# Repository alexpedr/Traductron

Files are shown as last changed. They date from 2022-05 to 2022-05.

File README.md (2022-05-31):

# Traductron



**Tabla de contenidos**
- [¿Qué es esto?](#id0)
- [Objetivo](#id8)
- [Componentes](#id1)
- [Circuito Hardware](#id9)
- [Arquitectura Sofware](#id10)
- [Requisitos](#id11)
- [Documentación](#id2)
- [Modo de empleo](#id3)
- [Autores](#id6)
- [Bibliografía](#id7)

## ¿Qué es esto? 
Traductron, como su propio nombre indica, traduce el Lenguaje de Signos Español a audio mediante una cámara.

El robot tiene la cámara en un brazo móvil. Este brazo baja y sube en función de la posición que capta del tronco superior (utilizando MediaPipe). Traductron también gira a la derecha o a la izquierda sobre sí mismo, así nunca perderá a la persona.

Si cuando el robot se enciende no encuentra a la persona, gira sobre sí mismo hasta encontrarla y realiza el procedimiento anterior para no perderla. Una vez encontrada, hace la traducción detectando la mano mediante MediPipe y la emite por el altavoz y repite el proceso en bucle.  

## Objetivo 
Nuestro objetivo es facilitar a las personas que se comunican mediante Lenguaje de Signos a mantener conversaciones con otras que no conozcan el lenguaje.

Buscamos que este colectivo gane independencia y que no tenga que disponer de un intérprete o de un familiar para poder hacer tareas cuotidianas como por ejemplo, ir a hacer una transacción a un banco. 

## Componentes 
El hardware que hemos usado para nuestro robot prototipo son los siguientes:

- 2 Motores Micro Metal LP
- 2 Ruedas base 
- Controlador de motores L289n
- Motor paso a paso 28BYJ-48
- Raspberry pi zero
- Cámara raspberry pi 
- Altavoz
- Amplificador
- Power Bank
- Pilas 9V
- Rueda loca metálica 
- Piezas 3D



No son los ideales, ya que tuvimos que escogerlos al principio del proyecto y no sabíamos bien bien cuáles iban mejor con nuestro software. También teníamos que adaptarnos a un presupuesto de 100 € proporcionado por la universidad.

Cabe destacar que, como usamos Mediapipe, la raspberry pi zero no es aconsejable usarla, por el hecho de que no se puede instalar esta librería en ella.

## Circuito Hardware 
Este es un circuito orientativo con nuestros componentes.



## Arquitectura Sofware
Así es como funciona nuesto robot traductron. Está dividido en los siguientes módulos:



1. Camara
Cada 1,5 segundos aproximadamente la camara toma fotos y estas se pasan al módulo de detector de tronco superior.

2. Detector tronco superior



Para realizar el movimiento de desplazamiento del robot y el de subir y bajar el brazo con la cámara, usamos también la librería MediaPipe, en este caso la opción de detectar solo el tronco superior.

De esta manera, creamos un documento de texto en el cual escribiremos 8 movimientos:

- Left - Up
- Left- Down
- Left
- Up
- Down
- Right - Up
- Right - Down
- Right

Este documento se pasa al módulo de movimiento.

3. Movimiento

A partir de los valores del documento, el robot se moverá de manera correspondiente. Una vez posicionado, se accede al módulo de detector de manos y traducción. Y se repite el procedimiento en bucle.

4. Detector de manos


A partir de la librería “MediaPipe”, detectamos los puntos de control de la mano y concretamente las coordenadas X e Y de cada uno de los puntos. Con este detector creamos de 0 nuestro dataset para poder entrenar posteriormente la Red Neuronal. 

5. Red Neuronal

A través de la librería sklearn podemos entrenar una red neuronal con la función MLPclassifier() donde le pasamos el Dataset con todas las letras y sus respectivas etiquetas. 

6. Salida de audio 

A través de las librerías gtts y playsound podemos reproducir, mediante audio, las letras en signos que le vayamos enseñando a la cámara. 
Creamos una función que, pasada la etiqueta de la letra, la pase al código ASCII y después la convierta a tipo char. Una vez hecho esto, le pasamos la letra a la función gTTS(), que grabará el audio en español. Guardamos el resultado en un archivo .mp3 y después con la función playsound() reproducimos el audio. 

## Requisitos 
- [NumPy](https://numpy.org/)
- [Pandas](https://aprendeconalf.es/docencia/python/manual/pandas/)
- [gTTs](https://pypi.org/project/gTTS/)
- [playSound](https://pypi.org/project/playsound/)
- [cv2](https://pypi.org/project/cv2-tools/)
- [MediaPipe](https://pypi.org/project/mediapipe/)
- [Pickle](https://docs.python.org/es/3/library/pickle.html)
- [sklearn](https://scikit-learn.org/stable/install.html)
- [Math](https://docs.python.org/es/3.10/library/math.html)
- [Copy](https://docs.python.org/es/3/library/copy.html)
- [Time](https://docs.python.org/es/3/library/time.html)

## Documentación 
Traductron, de momento, solo realiza la traducción del abecedario del Lenguaje de Signos Español.



Para poder hacer esto de manera correcta, tuvimos que hacer algunos cambios.

1. Hacer las letras sin movimiento, ya que no pudimos procesarlo.
2. Eliminamos las letras no necesárias, como: 'LL', 'RR', 'Ñ' y 'CH'.
3. Modificamos los signos de letras las letras que se confundian con otras.
4. Así ha quedado el abecedario que traduce Traductron.



## Modo de empleo 

En el caso de ejecutarlo en ordenador: 

1. Clonar  repositorio
2. Instalar librerias necesarias
3. Ejecutar los archivos en el siguiente orden:

  - 3.1.  Ejecutamos archivo "pythonPrueba2.py
    > Utilizamos este archivo para crear el DataSet, utilizando el findDetector.
  - 3.2. Ejecutamos el archivo "concatenarTablas.py"
    > Creamos un único archivo con todos los valores de las letras que hemos generado anteriormente.
  - 3.3. Ejecutamos el archivo  "redNeuronal.py"
    > Nos devuelve un valor de Accuracy para poder analizar la precisión de nuestro detector y generar un archivo sav que será la red neuronal que se utilizará.
  - 3.4. Ejecutamos el archivo "intentoTraductorFinal.py"
    > Utilizamos de nuevo el handDetector para el momento de detectar los puntos y pasamos los puntos a la red neuronal, que esta nos devuelve que letra es y reproducimos por audio.
 
 Una vez ejecutados estos archivos con el último de ellos podemos empezar a traducir
 
 (Los puntos 3.1, 3.2 y 3.3 no son necesarios de ejecutar, ya que proporcionamos una red neuronal y un dataset).

  4. En el caso de no disponer de una raspberry pi 3 o 4, como en nuestro caso, puedes usar las carpetas CLIENTE y SERVIDOR. El cliente se guardará en la raspberry y el servidor en tu ordenador. 
 
El cliente coje una fotografía creada por la cámara, la guarda y la envía al ordenador mediante sockets. El ordenador usará MediaPipe sobre esa foto recibida, clasifica ese signo y envía el resultado al altavoz. Una vez hecho esto, detecta el tronco superior y dependiendo de la posición de la persona, enviará un documento de texto u otro al módulo de movimiento, que se encuentra en la raspberry.

## Autores 

- Àlex Pedrola González
- Susana Sánchez Ropero
- Paula Martín Merino
- Pablo Ezequiel Britos

## Bibliografía 
This project has been inspired by the following Internet projects:

- [https://www.xataka.com/aplicaciones/asi-showleap-traductor-lengua-signos-a-texto-voz-tiempo-real-esta-cada-vez-cerca ](https://www.xataka.com/aplicaciones/asi-showleap-traductor-lengua-signos-a-texto-voz-tiempo-real-esta-cada-vez-cerca )

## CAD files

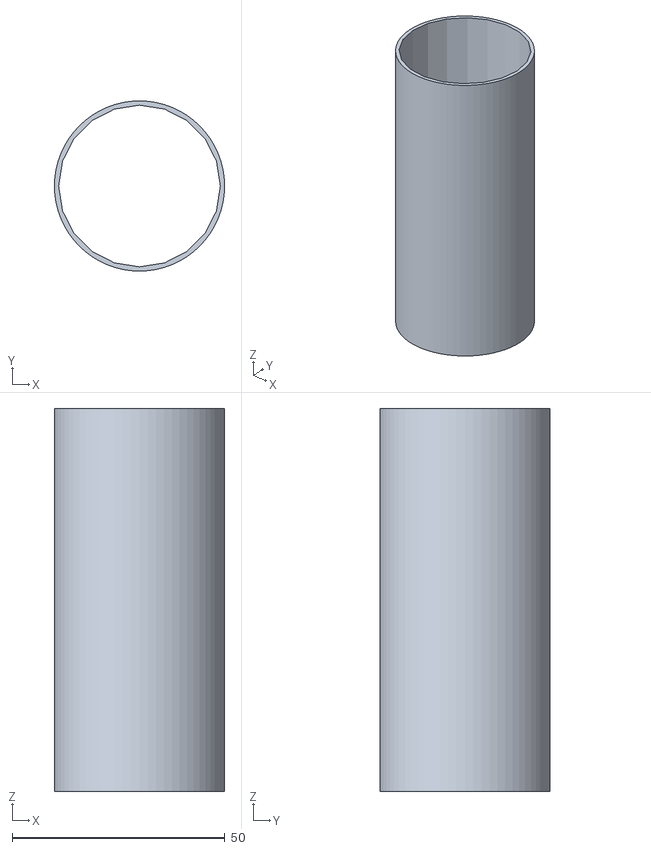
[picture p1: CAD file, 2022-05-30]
PIEZAS 3D/brazo.stl
40.0 x 40.0 x 90.0

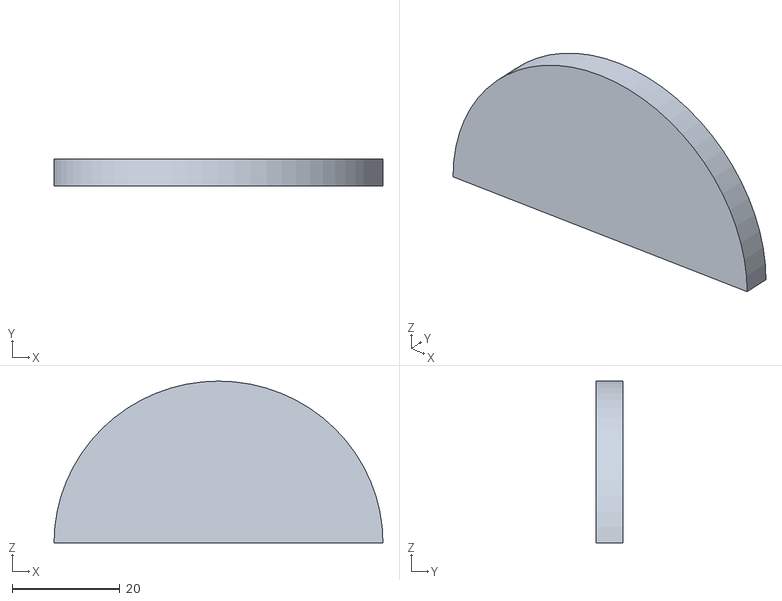
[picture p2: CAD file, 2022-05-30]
PIEZAS 3D/mediaLuna.stl
61.0 x 5.00 x 30.0

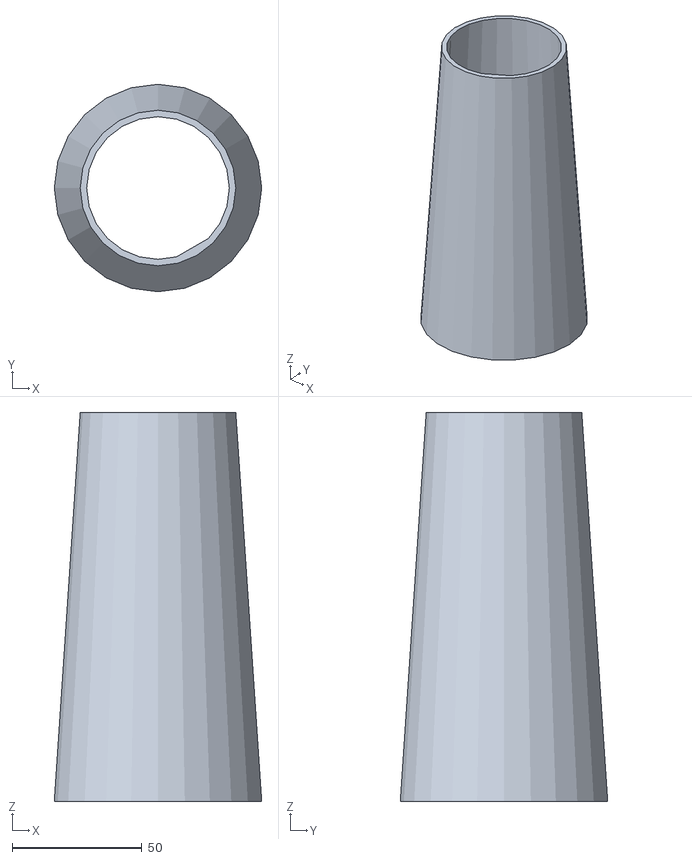
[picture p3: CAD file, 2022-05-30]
PIEZAS 3D/cono base.stl
80.0 x 80.0 x 150.0

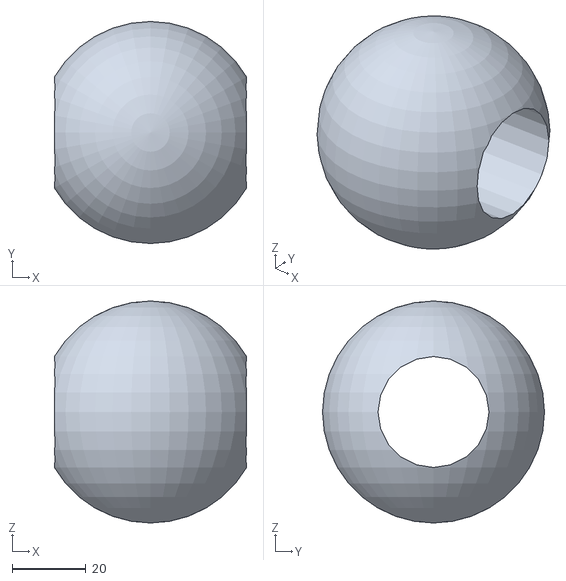
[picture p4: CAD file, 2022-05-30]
PIEZAS 3D/bola camara.stl
52.0 x 60.0 x 60.0

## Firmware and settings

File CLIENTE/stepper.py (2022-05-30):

#                                    .';:cc;.
#                                .,',;lol::c.
#                                ;';lddddlclo
#                                lcloxxoddodxdool:,.
#                                cxdddxdodxdkOkkkkkkkd:.
#                         .ldxkkOOOOkkOO000Okkxkkkkx:.
#                    .lddxkkOkOOO0OOO0000Okxxxxkkkk:
#                 'ooddkkkxxkO0000KK00Okxdoodxkkkko
#                .ooodxkkxxxOO000kkkO0KOxolooxkkxxkl
#                lolodxkkxxkOx,.                .lkdolodkkxxxO.
#                doloodxkkkOk                            ....        .,cxO;
#                ddoodddxkkkk:                        ,oxxxkOdc'..o'
#                :kdddxxxxd,    ,lolccldxxxkkOOOkkkko,
#                 lOkxkkk;    :xkkkkkkkkOOO000OOkkOOk.
#                    ;00Ok' 'O000OO0000000000OOOO0Od.
#                        .l0l.;OOO000000OOOOOO000000x,
#                                .'OKKKK00000000000000kc.
#                                        .:ox0KKKKKKK0kdc,.
#                                                         ...
#
# Author: peppe8o
# Date: Feb 24th, 2020
# version: 1.2

# Import required libraries
import sys
import time
import RPi.GPIO as GPIO

# define variables
chan_list = [27,22,10,9] # GPIO ports to use
delay=.0015 # delay between each sequence step

# Use BCM GPIO references
# instead of physical pin numbers
GPIO.setmode(GPIO.BCM)

# Set all pins as output
for pin in chan_list:
    print("Setup pins")
    GPIO.setup(pin,GPIO.OUT)

#initialize array for sequence shift
arr1 = [1,1,0,0]
arr2 = [0,1,0,0]

def move():
    global arr1 # enables the edit of arr1 var inside a function
    global arr2 # enables the edit of arr2 var inside a function
    arrOUT = arr1[3:]+arr1[:3] # rotates array values of 1 digit
    arr1 = arr2
    arr2 = arrOUT
    GPIO.output(chan_list, arrOUT)
    time.sleep(delay)
# Start main loop
def bajar():
    global arr1 # enables the edit of arr1 var inside a function
    global arr2 # enables the edit of arr2 var inside a function
    arrOUT = arr1[1:]+arr1[:1] # rotates array values of 1 digit
    arr1 = arr2
    arr2 = arrOUT
    GPIO.output(chan_list, arrOUT)
    time.sleep(delay)
class stepper:
    def __init__(self):
        self.contador = 0
    def subirCamaraInicial(self):
        while(self.contador < 1000):
            move()
            self.contador += 1
    def bajarCamaraFinal(self):
        while(self.contador > 0):
            bajar()
            self.contador -= 1
    def subirXPuntos(self,cantidadPuntos):
        cantidad = 0
        while(self.contador < 1800 and cantidad < cantidadPuntos):
          self.contador += 1
          move()
          cantidad += 1
    def bajarXPuntos(self,cantidadPuntos):
        cantidad = 0
        while(self.contador > 100 and cantidad < cantidadPuntos):
          self.contador -= 1
          bajar()
          cantidad += 1

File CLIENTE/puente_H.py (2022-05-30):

#!/usr/bin/env python

import RPi.GPIO as GPIO
import os
import time

class ruedas:
	def __init__(self):
		self.m2 = 2
		self.e2 = 3
		self.e1 = 4
		self.m1 = 17
		GPIO.setmode(GPIO.BCM)

		GPIO.setup(self.m2,GPIO.OUT)
		GPIO.setup(self.e2,GPIO.OUT)

		GPIO.setup(self.m1,GPIO.OUT)
		GPIO.setup(self.e1,GPIO.OUT)

		self.pwm_a = GPIO.PWM(self.e1,500)
		self.pwm_b = GPIO.PWM(self.e2,500)

		self.pwm_a.start(0)
		self.pwm_b.start(0)


	def giro_FavorRelojMotorA(self):
		GPIO.output(self.m1,False)
	def giro_ContraRelojMotorA(self):
		GPIO.output(self.m1,True)
	def giro_FavorRelojMotorB(self):
		GPIO.output(self.m2,False)
	def giro_ContraRelojMotorB(self):
		GPIO.output(self.m2,True)

  

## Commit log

2022-04-19 Prueba de push
2022-04-19 Carpeta de codigo añadida
2022-04-19 Excels añadidos
    [H.xlsx, I.xlsx, J.xlsx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]
2022-04-19 Codigo de concatenar tablas modificado, he cambiado la ruta
2022-04-19 Modificado el concatenarTablas
2022-04-27 Hecho el codigo que pasada una frase te crea un audio y lo reproduce, también está hecha la función que llamaremos cuando hayamos predicho la letra
2022-04-27 Letras puestas en la carpeta y enunmeradas
    [A.xlsx, B.xlsx, C.xlsx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]
2022-05-02 red neuronal de 224/250 guardada
2022-05-02 red neuronal de 232/250 actualizada
2022-05-02 Cambiada la cantidad de neuronas en la capa
2022-05-03 prueba de traductor
2022-05-03 letras pablo con etiqueta
    [O.xlsx, P.xlsx, Q.xlsx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]
2022-05-04 Letras de Pablo cambiadas
    [O.xlsx, Q.xlsx, R.xlsx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]
2022-05-04 Letras de pablo en otra carpeta
    [Q.xlsx, R.xlsx, S.xlsx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]
2022-05-14 Nuevo dataset preparado
    [A1.xlsx, B1.xlsx, C1.xlsx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]
2022-05-15 Segunda tanda añadida
    [A2.xlsx, B2.xlsx, C2.xlsx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]
2022-05-18 letras 3 cambiadas
    [A3.xlsx, B3.xlsx, C3.xlsx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]
2022-05-18 Funcionan todas las letras menos T y F que las confunde
2022-05-30 Todo reestructurado
    [final.xlsx]
2022-05-30 carpeta piezas 3d añadida
    [bola camara.stl, brazo.stl, cono base.stl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]
